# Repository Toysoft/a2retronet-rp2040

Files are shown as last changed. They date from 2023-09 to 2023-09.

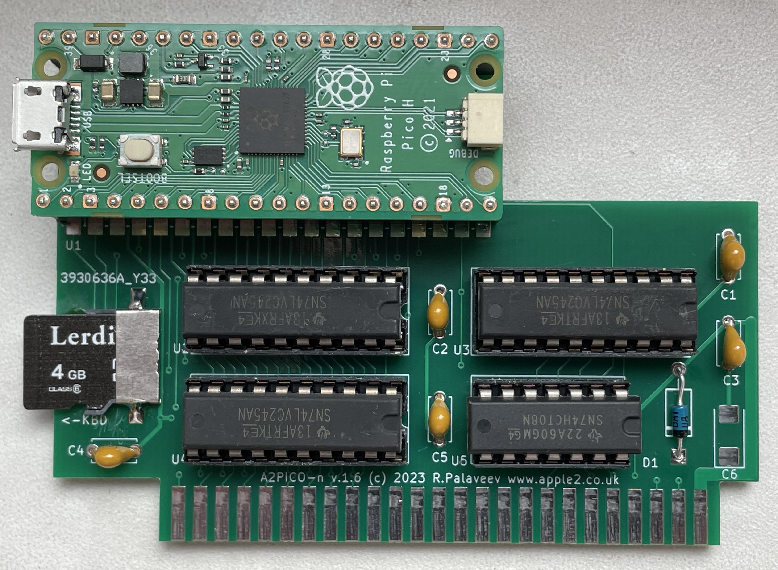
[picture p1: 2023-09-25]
A2PICO-n.v1.6/A2PICO-n.v1.6.jpg

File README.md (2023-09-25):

# A2retroNET RP2040

_Directly connecting the [Raspberry Pi RP2040](https://www.raspberrypi.com/products/rp2040/) to the Apple II slot bus_

[Demo Program](demo/README.md)

This is a HW implementation of Oliver Schmidt's recommended designs.

Version 1.4 is the innitial design with 3x 74LVC245 and 1x 74HC08 to prove the concept. However it is obsolete as it does not switch off the Expansion ROM ($C800-$CFFF), which is always available and could cause data bus conlisions if used with other cards that use this memory space.

Version 1.5 switches off the Expansion ROM ($C800-$CFFF) when $CFFF is accessed or when reset is issued, and switches it back on again when the slot memory is accessed (IOSelect).

Version 1.6 combines 3 of the logic chips into a PLD. 74LS08, 74LS133 and 74LS02 are replaced by ATF22V10.

The RPI usage is as follows:

| GPIO | Usage |
|:---|:---|
| 0 |  UART TX  |
| 1 |  UART RX  |
| 2 - 13  | A0 - A11  |
| 14 | R/W |
| 15 - 22 | D0 - D7 |
| 26 | ENBL |
| 27 | IRQ |
| 28 | RES |

Version "n" has support for a MicroSD card with **no** ExtROM capability.

The RPI usage of the "n" versions is as follows:

| GPIO | Usage |
|:---|:---|
| 0 |  SPI RX |
| 1 |  SPI CSn  |
| 2 |  SPI SCK  |
| 3 |  SPI TX |
| 4 |  NMI |
| 5 - 12  | A0 - A7 |
| 13 | DEVSEL |
| 14 | R/W |
| 15 - 22 | D0 - D7 |
| 26 | ENBL |
| 27 |  IRQ |
| 28 |  RES |

There is a suggested driver for a ProDOS block device for the "n" version.

However, there is a current need for development of a firmware for the "n" version for the RPI Pico to drive the IO with the A2 and the MicroSD card.

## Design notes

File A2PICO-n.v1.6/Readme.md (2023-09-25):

This is a HW implementation with support for a MicroSD card and **no** ExtROM capability.

The pinout of the "n" versions is as follows:

| GPIO | Usage |
|:---|:---|
| 0 |  SPI RX |
| 1 |  SPI CSn  |
| 2 |  SPI SCK  |
| 3 |  SPI TX |
| 4 |  NMI |
| 5 - 12  | A0 - A7 |
| 13 | DEVSEL |
| 14 | R/W |
| 15 - 22 | D0 - D7 |
| 26 | ENBL |
| 27 |  IRQ |
| 28 |  RES |

There is a suggested driver for a ProDOS block device in the file Firmware files .BIN and .ASM.
The Read/Write buffer is the 16-byte DevSel memory C0NX (N=slot+6). The volume, 512-byte Pro-DOS block selecttion and the 16-byte offsett within the block are done by the following writes (S=slot):

CS00 - volume $00(D1) or $80(D2)

CS01 - low byte block

CS02 - high byte block

CS03 - 16-byte offset within block 

However, there is a current need for development of a firmware for this "n" version for the RPI Pico to drive the IO with the A2 and the MicroSD card.

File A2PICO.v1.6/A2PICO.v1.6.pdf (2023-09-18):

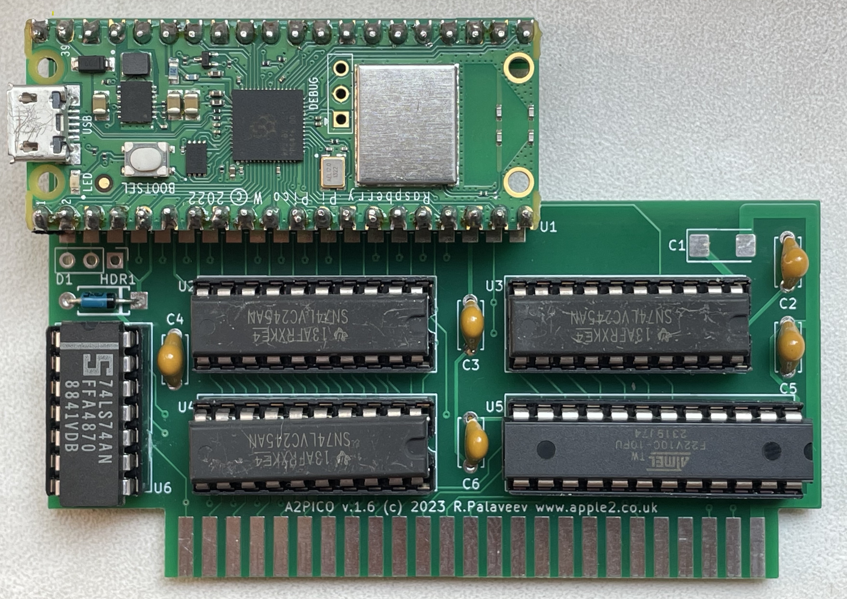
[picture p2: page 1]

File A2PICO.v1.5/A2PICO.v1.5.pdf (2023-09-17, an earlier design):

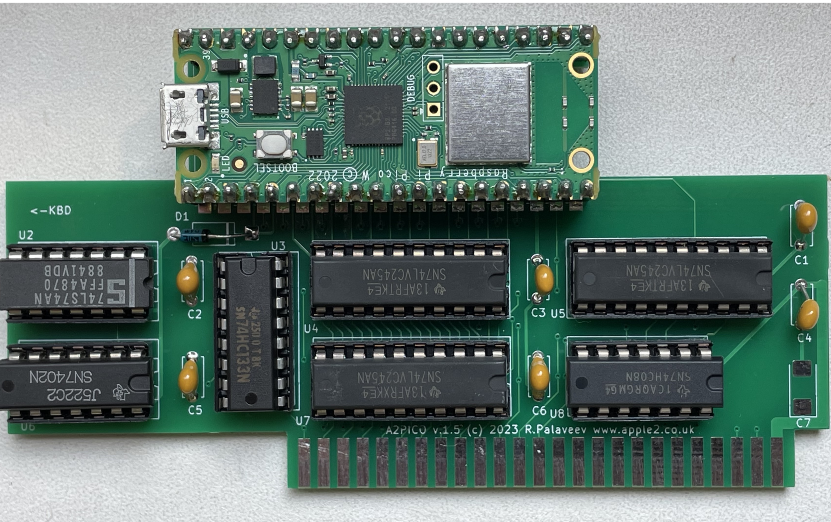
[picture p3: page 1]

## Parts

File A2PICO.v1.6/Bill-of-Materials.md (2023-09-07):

|Qty|Designator|Item|Package|Description|
|---|---|---|---|---|
|1x|C1|6.3V 220uF X5R|0805|Multilayer Ceramic Capacitor|
|5x|C2-C6|50V 100nF X7R|0402|Multilayer Ceramic Capacitor|
|1x|D1|SS14F|SMAF|40V 550mV @ 1A Shottkey Barrier Diode|
|1x|U1|Pico-W|Module|Raspberry Pi Pico or Pico-W module (no pins)|
|3x|U2-U4|SN74LVC245A|PDIP-20|Texas Instruments SN74LVC245A Octal Bus Transceiver With 3-State Outputs|
|1x|U5|ATF22V10C-10PC|PDIP-24|Microchip ATF22V10C PLD|
|1x|U6|SN74LS74|PDIP-14|Dual Positive-Edge-Triggered D Flip-Flops with Pr, Cl and Complementary Outputs|
|1x|HDR1|3-pin Header|HD-3|TH PinHeader_1x03_P2.54mm_Vertical|

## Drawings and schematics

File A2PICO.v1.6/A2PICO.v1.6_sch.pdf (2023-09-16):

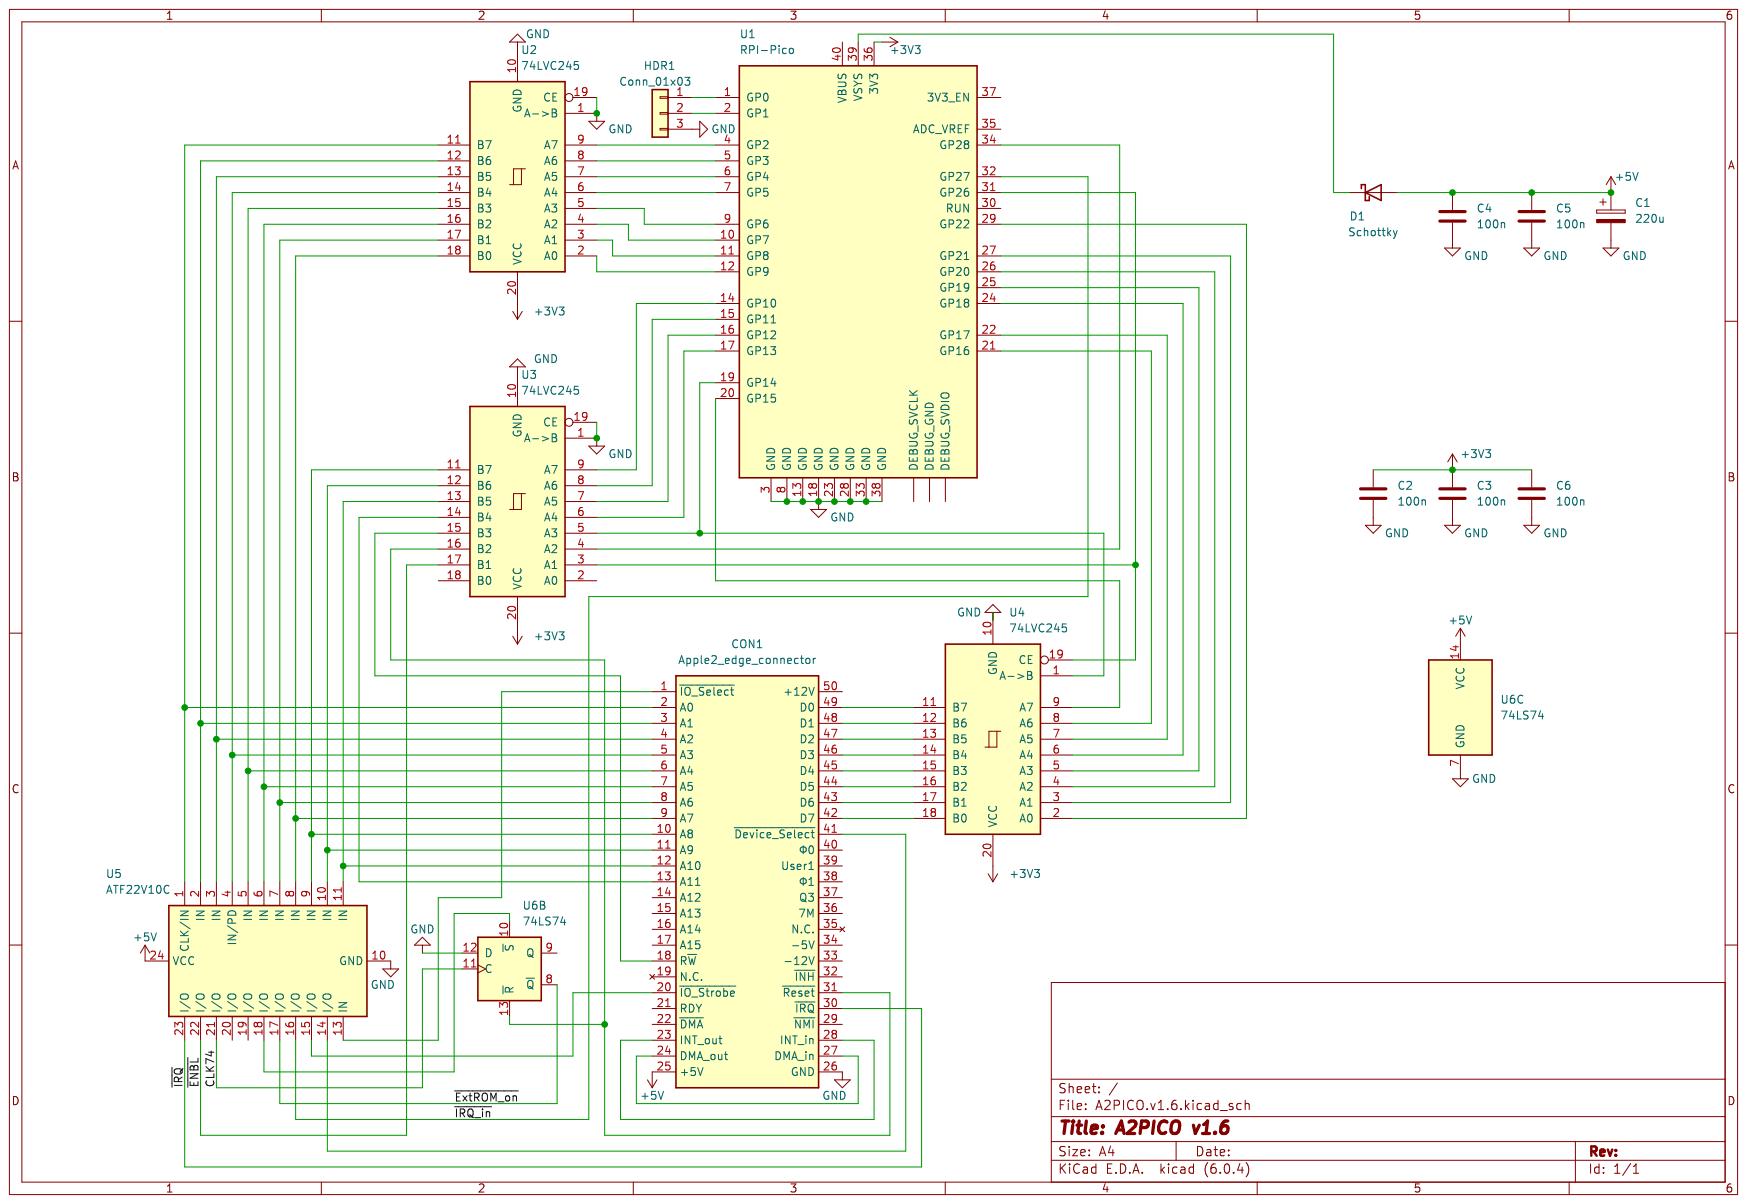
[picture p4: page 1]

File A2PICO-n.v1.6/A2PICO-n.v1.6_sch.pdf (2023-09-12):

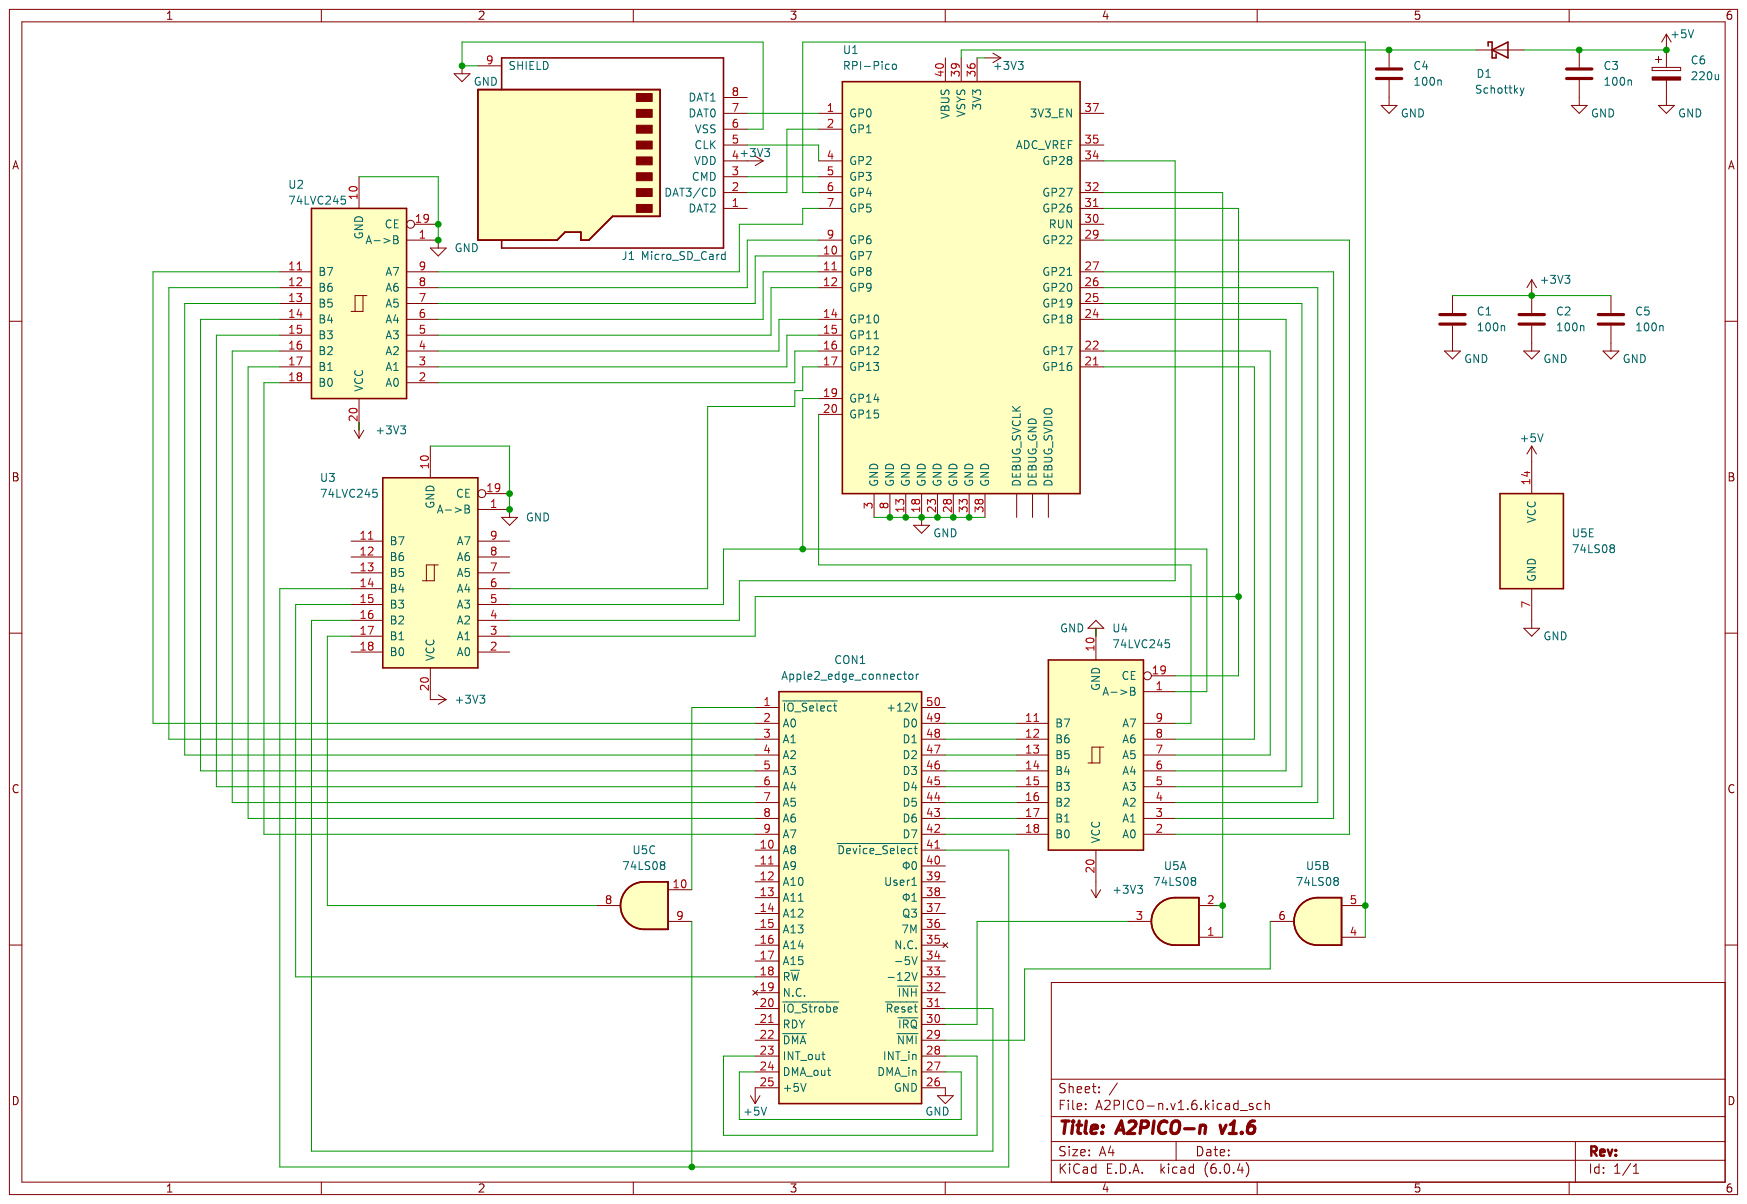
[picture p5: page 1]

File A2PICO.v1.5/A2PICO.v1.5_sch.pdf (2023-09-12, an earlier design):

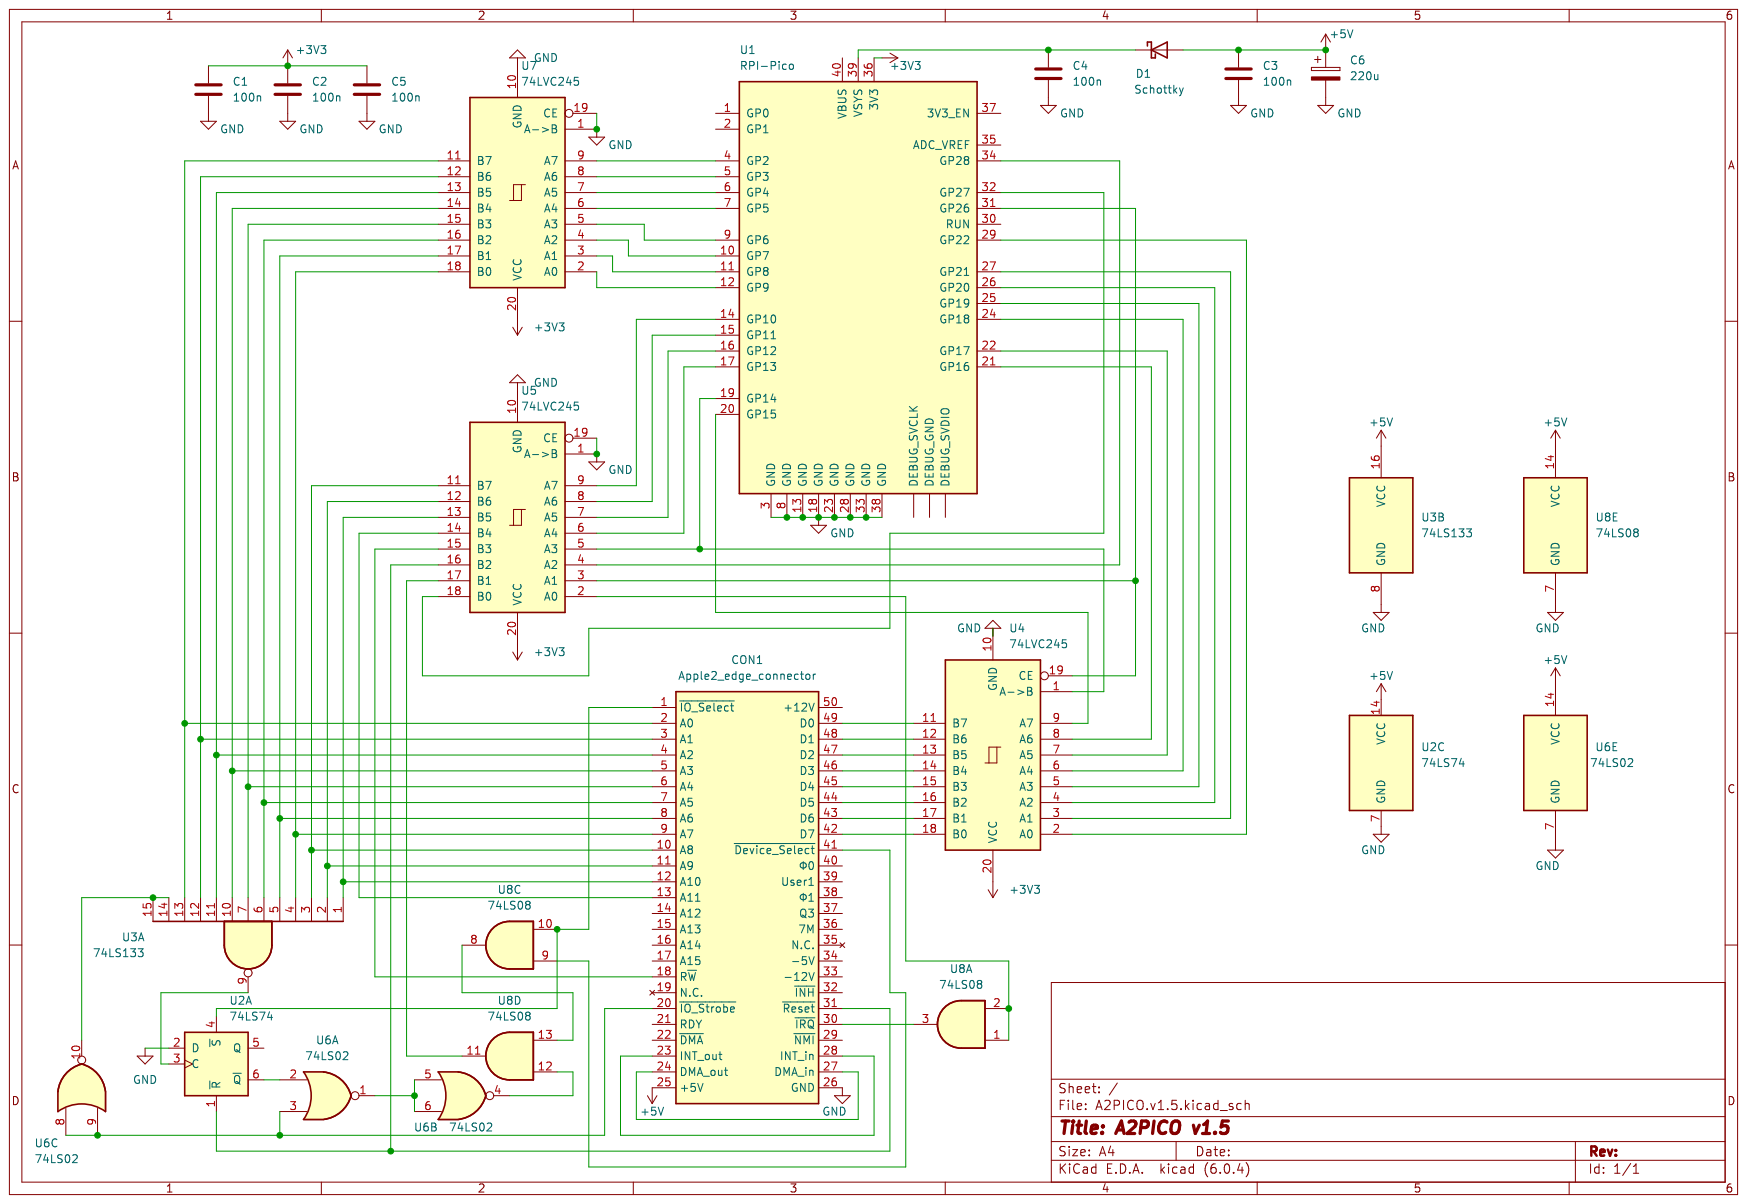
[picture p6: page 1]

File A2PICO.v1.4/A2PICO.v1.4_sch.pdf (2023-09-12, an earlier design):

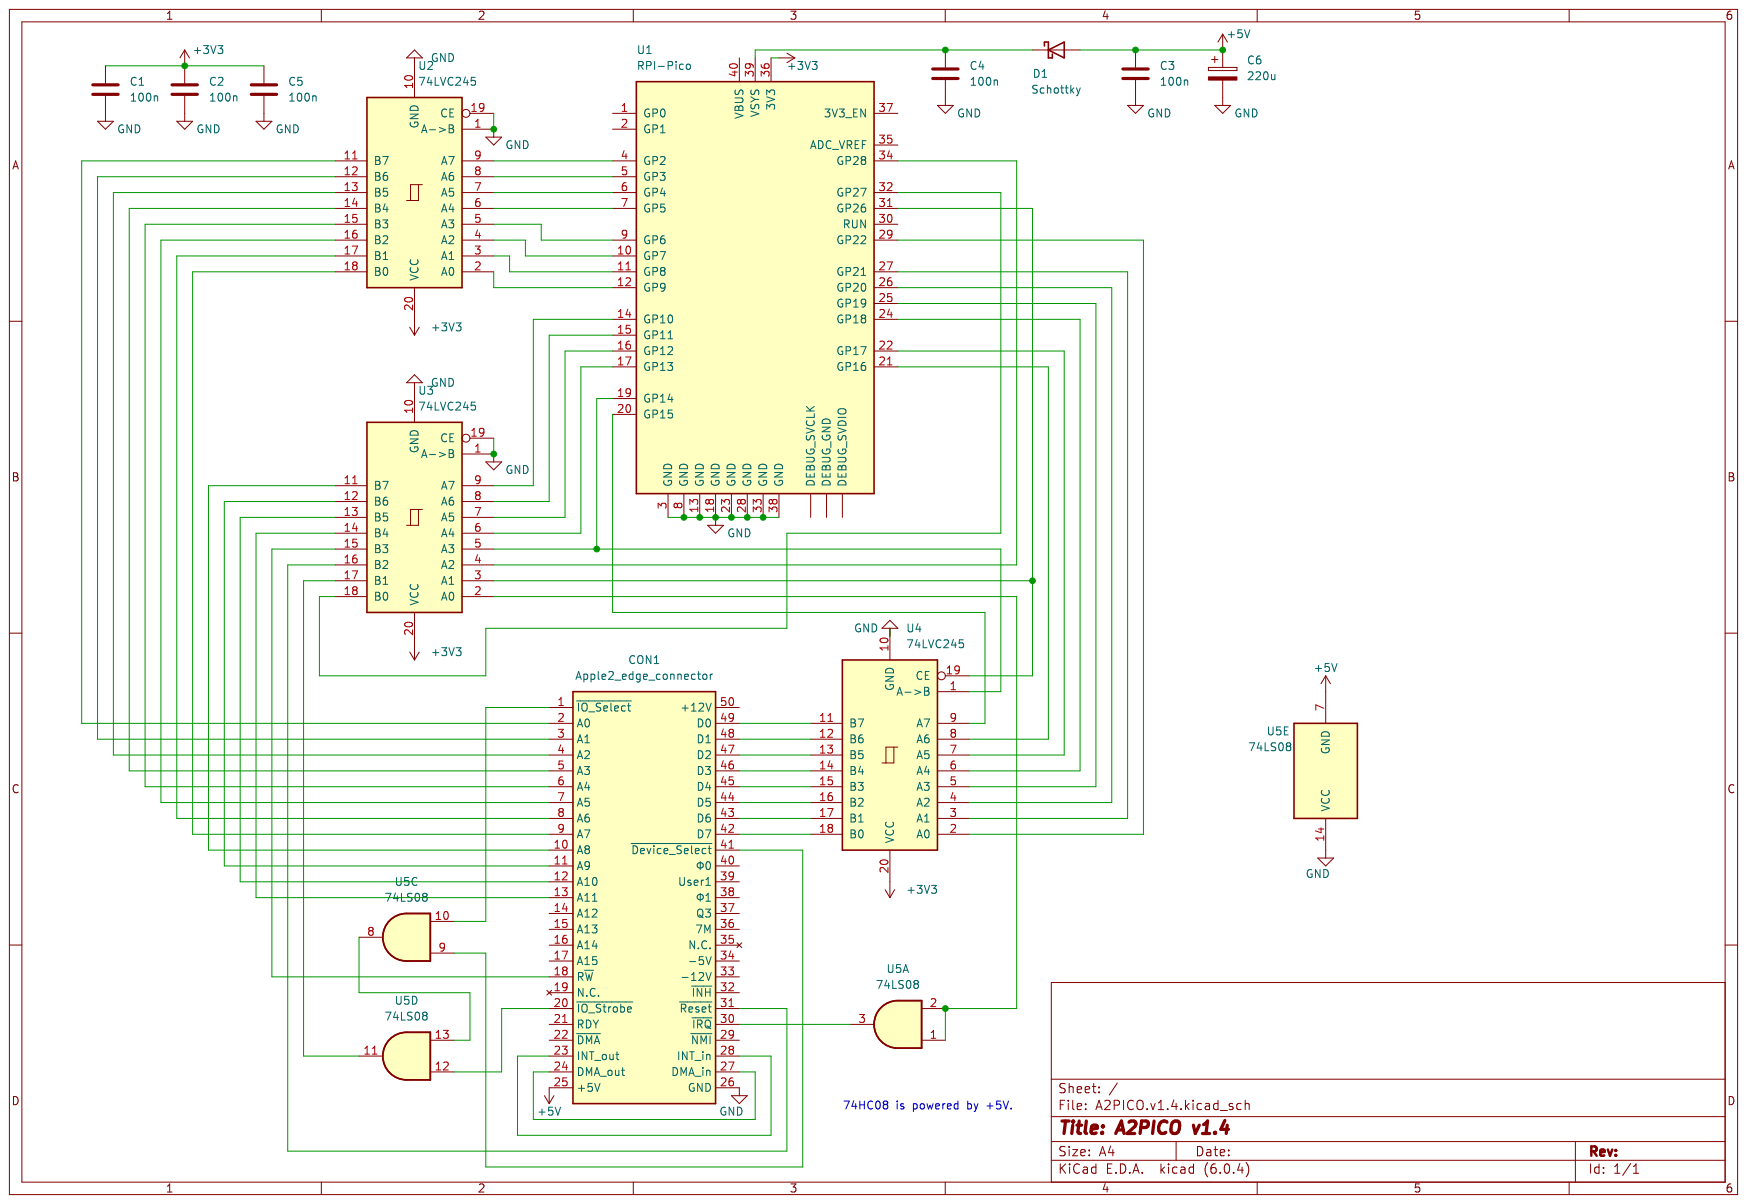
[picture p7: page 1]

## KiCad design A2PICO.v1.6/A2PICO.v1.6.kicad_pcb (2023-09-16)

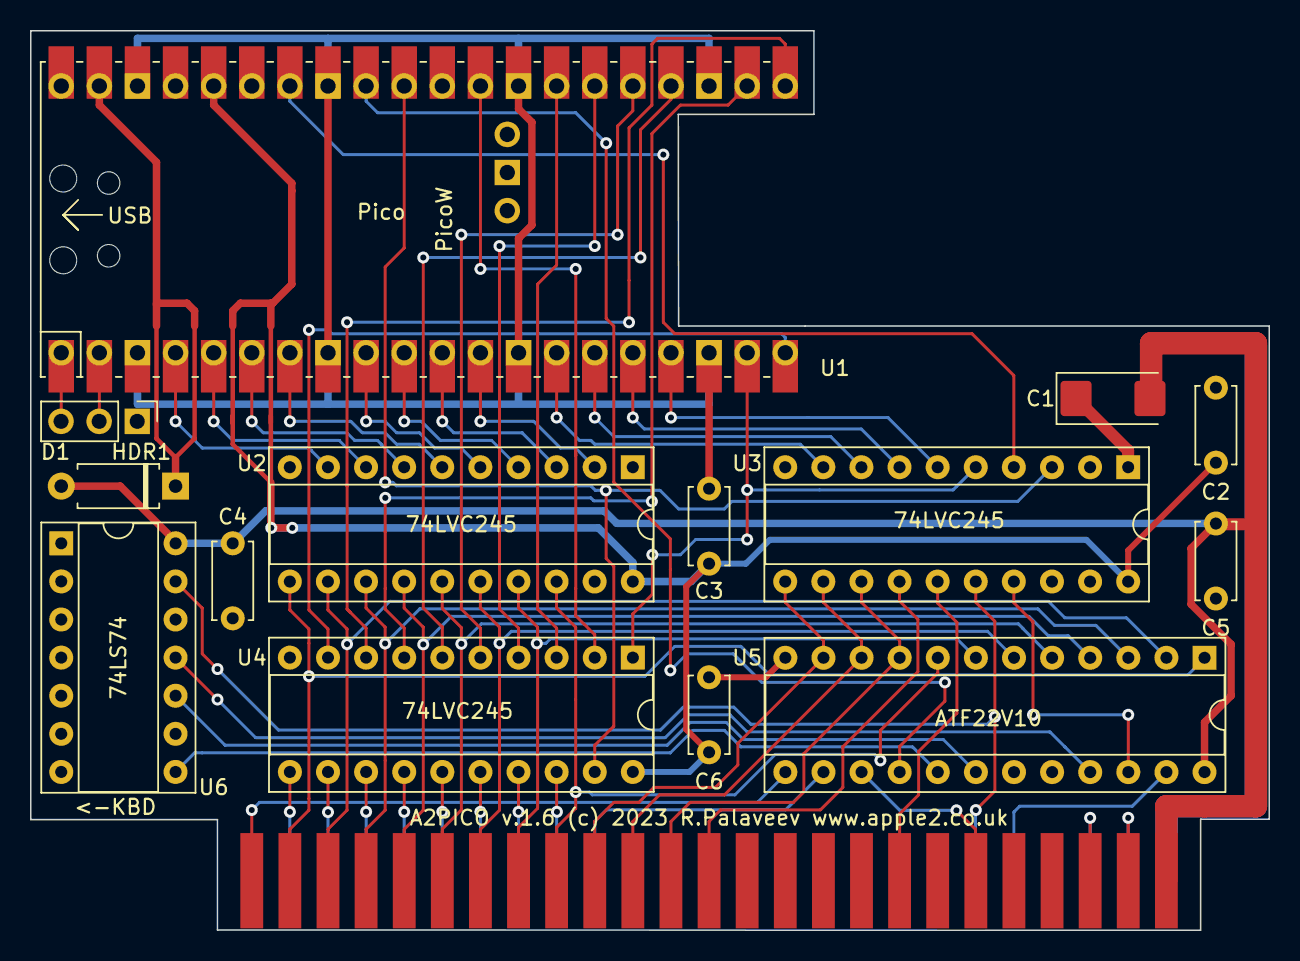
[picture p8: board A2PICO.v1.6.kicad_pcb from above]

Board: 2 copper layers, 82.5 x 60.0 mm, 14 parts (0 on the bottom side), 4 nets.

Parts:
C1: 220uF; CP_EIA-6032-15_Kemet-U
C2, C3, C4, C5, C6: 100n; C_Disc_D5.0mm_W2.5mm_P5.00mm
D1: D_A-405_P7.62mm_Horizontal
HDR1: PinHeader_1x03_P2.54mm_Vertical
U1: PicoW; RPi_PicoW_SMD_TH
U2, U3, U4: 74LVC245; DIP-20_W7.62mm_Socket
U5: ATF22V10; DIP-24_W7.62mm_Socket
U6: 74LS74; DIP-14_W7.62mm_Socket

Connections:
3.3V: C2.1, C3.1, C6.1, U1.36 (3V3), U2.20, U3.20, U4.20
5V: C1.2, C4.2, C5.2, D1.2, U5.24, U6.14
GND: C1.1, C2.2, C3.2, C4.1, C5.1, C6.2, HDR1.1, U1.3 (GND), U1.8 (GND), U1.13 (GND), U1.18 (GND), U1.23 (GND), U1.28 (GND), U1.33 (AGND), U1.38 (GND), U2.1, U2.10, U2.19, U3.1, U3.10, U3.19, U4.10, U5.12, U6.2, U6.7, U6.12
VSYS: D1.1, U1.39 (VSYS)

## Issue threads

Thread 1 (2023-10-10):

Only a few ideas.

Hubidrei, 2023-10-10:
Why did not you include the Flipflop also into the GAL/PAL like A2Heaven does in their PicoPAL?
Another idea is DMA-access.
Then why use the iostrobe, devsel and iosel?
You can let the RP2040 sniff the bus and let its software manage the softswitches, memory and io?
The Neo6502 does this in extreme it consists of a 65C02, bus drivers and a RP2040 where the rp2040 can emulate the whole Apple ][ and has HDMI output.

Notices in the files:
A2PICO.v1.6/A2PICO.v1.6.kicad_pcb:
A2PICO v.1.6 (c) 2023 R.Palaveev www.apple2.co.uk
